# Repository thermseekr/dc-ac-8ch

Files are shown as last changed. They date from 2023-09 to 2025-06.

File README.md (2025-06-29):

# DC-AC-8CH

Triac board with 8x 24 VDC inputs and 8x 220 AC outputs.

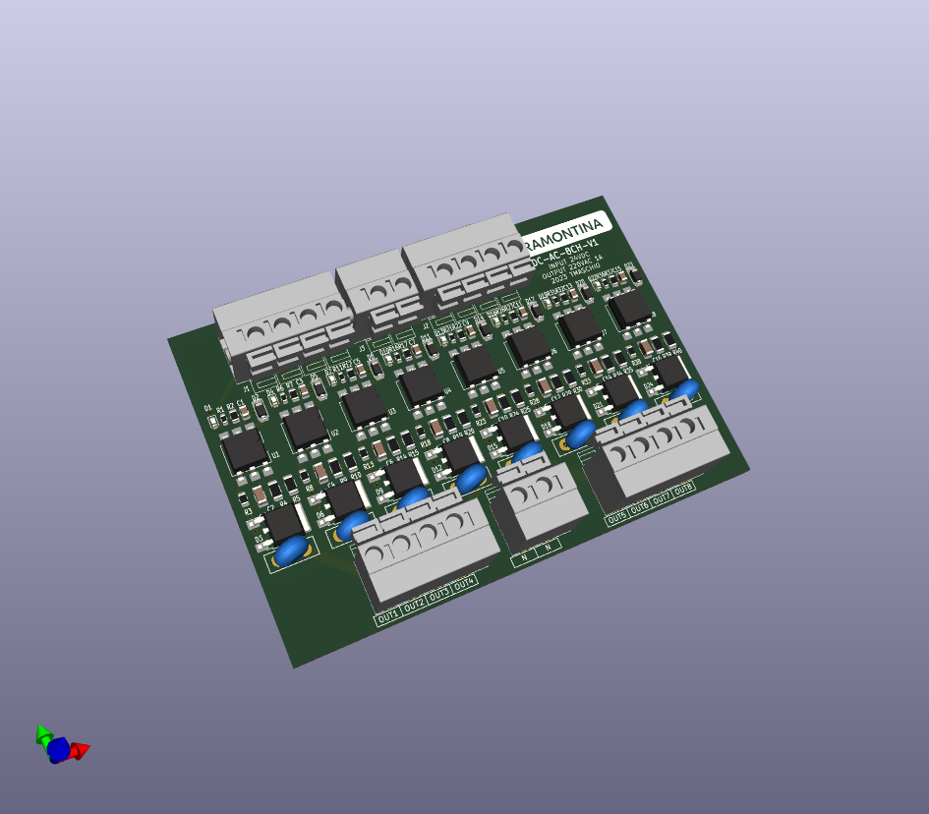
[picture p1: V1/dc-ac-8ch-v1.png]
DC-AC-8CH-V1


## LICENSE

This project is licensed under the [Creative Commons BY-NC 4.0 License](https://creativecommons.org/licenses/by-nc/4.0/).
Commercial use is not permitted without prior written consent. See the [LICENSE.txt](LICENSE.txt) file for details.

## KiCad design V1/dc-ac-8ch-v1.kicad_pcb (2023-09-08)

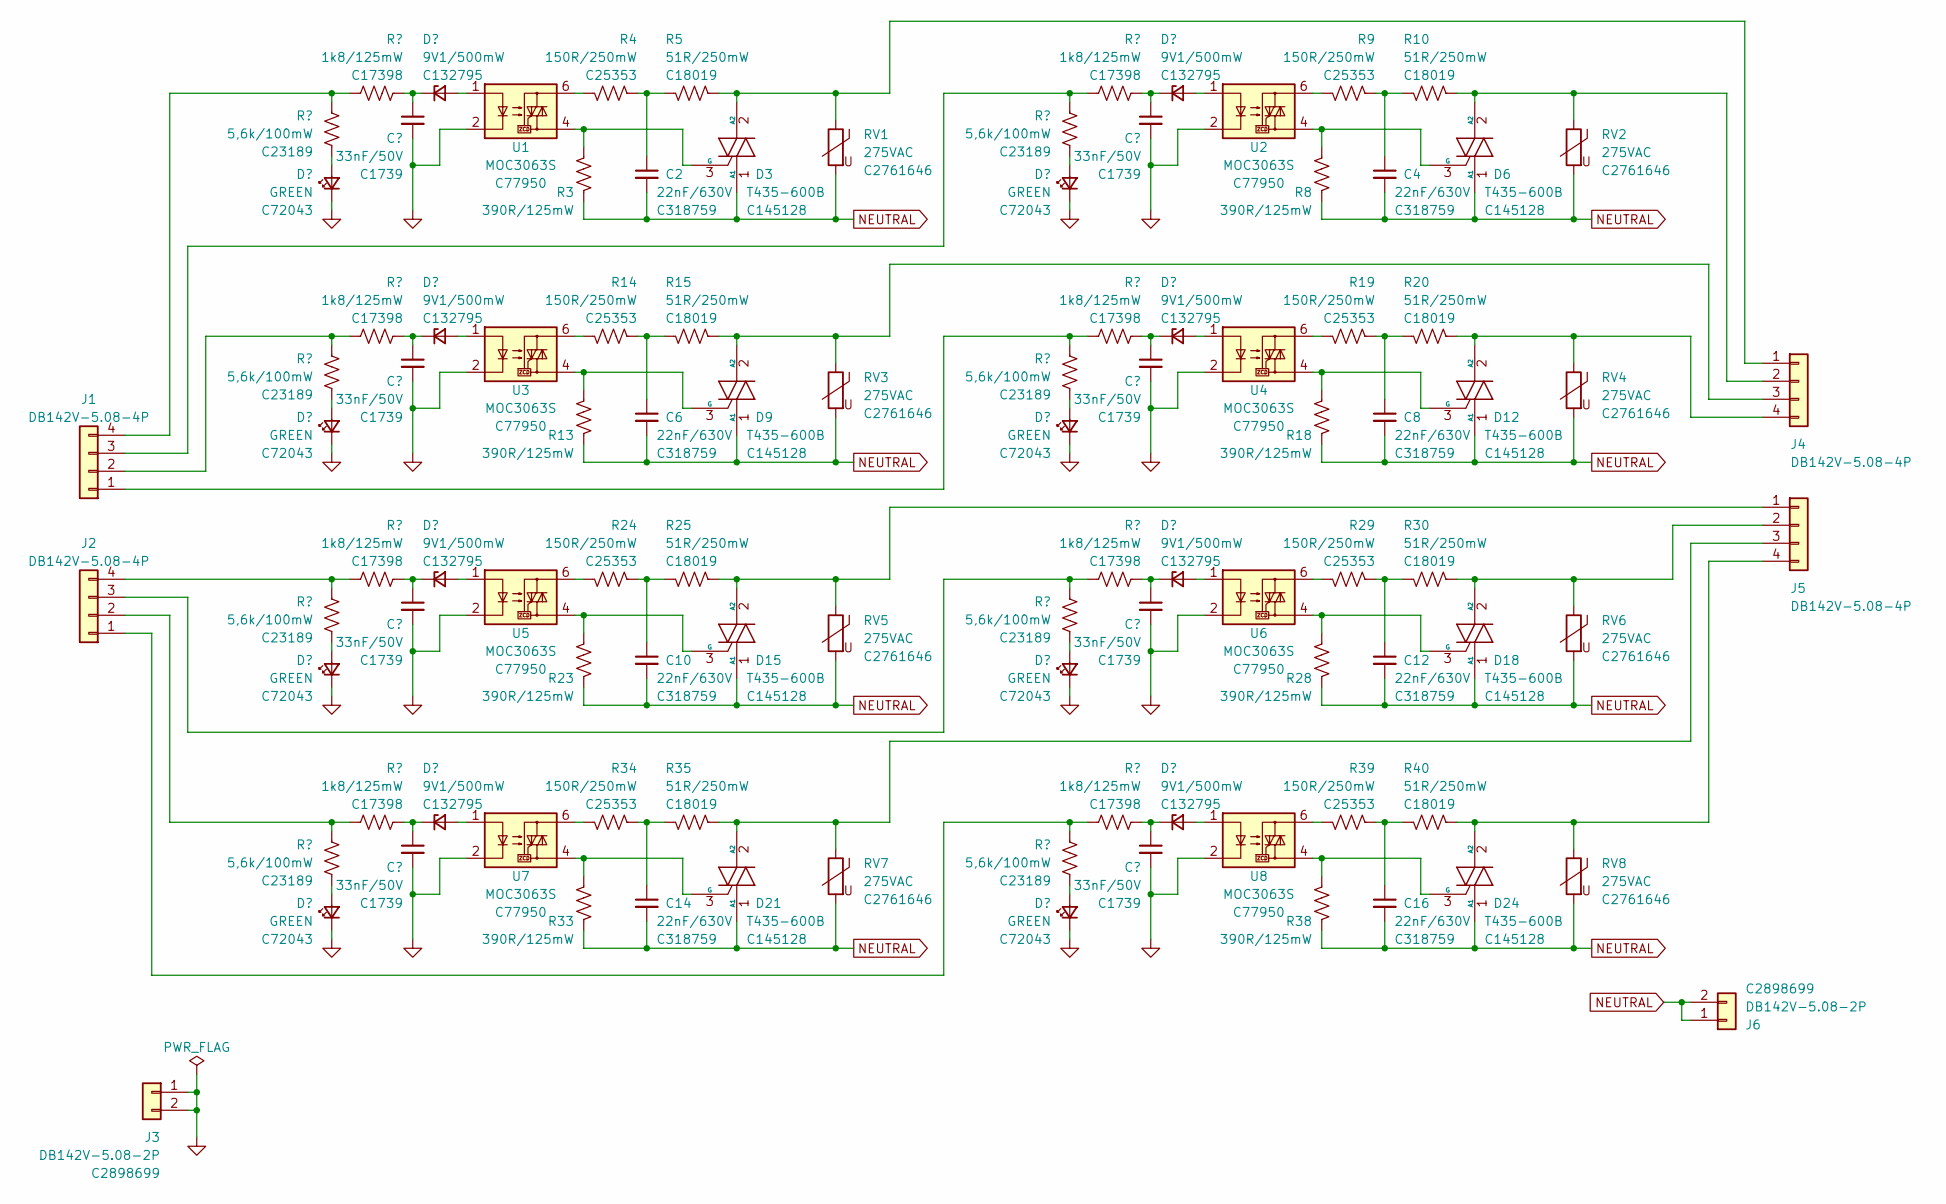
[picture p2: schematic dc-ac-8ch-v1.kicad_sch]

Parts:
C1, C3, C5, C7, C9, C11, C13, C15: 33nF/50V; C_0805_2012Metric; LCSC Part # C1739
C2, C4, C6, C8, C10, C12, C14, C16: 22nF/630V; C_1206_3216Metric; Mfr Part # CL31B223KHHNNNE; JLCPCB BOM 1
D1, D4, D7, D10, D13, D16, D19, D22: GREEN; LED_0603_1608Metric; Mfr Part # 19-217/GHC-YR1S2/3T; LCSC Part # C72043
D2, D5, D8, D11, D14, D17, D20, D23: 9V1/500mW; D_SOD-123; Mfr Part # MMSZ9V1T1G; JLCPCB BOM 1
D3, D6, D9, D12, D15, D18, D21, D24: T435-600B; TO-252-2; Mfr Part # T435-600B-TR; JLCPCB BOM 1
J1, J2, J4, J5: DB142V-5.08-4P; TerminalBlock_Dibo_DB142V-5.08-4P_1x04_P5.08mm_Vertical; Mfr Part # DB142V-5.08-4P; JLCPCB BOM 1
J3, J6: DB142V-5.08-2P; TerminalBlock_Dibo_DB142V-5.08-2P_1x02_P5.08mm_Vertical; Mfr Part # DB142V-5.08-2P; JLCPCB BOM 1
R1, R6, R11, R16, R21, R26, R31, R36: 5,6k/100mW; R_0603_1608Metric; Mfr Part # 0603WAF5601T5E; LCSC Part # C23189
R2, R7, R12, R17, R22, R27, R32, R37: 1k8/125mW; R_0805_2012Metric; Mfr Part # 0805W8F1801T5E; LCSC Part # C17398
R3, R8, R13, R18, R23, R28, R33, R38: 390R/125mW; R_0805_2012Metric; Mfr Part # 0805W8F3900T5E; JLCPCB BOM 1
R4, R9, R14, R19, R24, R29, R34, R39: 150R/250mW; R_1206_3216Metric; Mfr Part # 1206W4J0151T5E; JLCPCB BOM 1
R5, R10, R15, R20, R25, R30, R35, R40: 51R/250mW; R_1206_3216Metric; Mfr Part # 1206W4F510JT5E; JLCPCB BOM 1
RV1, RV2, RV3, RV4, RV5, RV6, RV7, RV8: 275VAC; RV_Disc_D9.50mm_W3.6mm_P5.08mm; Mfr Part # RM07D431KC1IE100; JLCPCB BOM 1
U1, U2, U3, U4, U5, U6, U7, U8: MOC3063S; SMDIP-6_W9.53mm_Clearance8mm; Mfr Part # MOC3063S-TA1; JLCPCB BOM 1

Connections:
GND: C1.2, C3.2, C5.2, C7.2, C9.2, C11.2, C13.2, C15.2, D1.1 (K), D4.1 (K), D7.1 (K), D10.1 (K), D13.1 (K), D16.1 (K), D19.1 (K), D22.1 (K), J3.1, J3.2, U1.2, U2.2, U3.2, U4.2, U5.2, U6.2, U7.2, U8.2
NEUTRAL: C2.2, C4.2, C6.2, C8.2, C10.2, C12.2, C14.2, C16.2, D3.1 (A1), D6.1 (A1), D9.1 (A1), D12.1 (A1), D15.1 (A1), D18.1 (A1), D21.1 (A1), D24.1 (A1), J6.1, J6.2, R3.2, R8.2, R13.2, R18.2, R23.2, R28.2, R33.2, R38.2, RV1.2, RV2.2, RV3.2, RV4.2, RV5.2, RV6.2, RV7.2, RV8.2
unnamed: C2.1, R4.1, R5.2
unnamed: C4.1, R9.1, R10.2
unnamed: C6.1, R14.1, R15.2
unnamed: C8.1, R19.1, R20.2
unnamed: C10.1, R24.1, R25.2
unnamed: C12.1, R29.1, R30.2
unnamed: C14.1, R34.1, R35.2
unnamed: C16.1, R39.1, R40.2
unnamed: D1.2 (A), R1.2
unnamed: D2.2 (A), U1.1
unnamed: C1.1, D2.1 (K), R2.1
unnamed: D3.2 (A2), J4.1, R5.1, RV1.1
unnamed: D3.3 (G), R3.1, U1.4
unnamed: D4.2 (A), R6.2
unnamed: D5.2 (A), U2.1
unnamed: C3.1, D5.1 (K), R7.1
unnamed: D6.2 (A2), J4.2, R10.1, RV2.1
unnamed: D6.3 (G), R8.1, U2.4
unnamed: D7.2 (A), R11.2
unnamed: D8.2 (A), U3.1
unnamed: C5.1, D8.1 (K), R12.1
unnamed: D9.2 (A2), J4.3, R15.1, RV3.1
unnamed: D9.3 (G), R13.1, U3.4
unnamed: D10.2 (A), R16.2
unnamed: D11.2 (A), U4.1
unnamed: C7.1, D11.1 (K), R17.1
unnamed: D12.2 (A2), J4.4, R20.1, RV4.1
unnamed: D12.3 (G), R18.1, U4.4
unnamed: D13.2 (A), R21.2
unnamed: D14.2 (A), U5.1
unnamed: C9.1, D14.1 (K), R22.1
unnamed: D15.2 (A2), J5.1, R25.1, RV5.1
unnamed: D15.3 (G), R23.1, U5.4
unnamed: D16.2 (A), R26.2
unnamed: D17.2 (A), U6.1
unnamed: C11.1, D17.1 (K), R27.1
unnamed: D18.2 (A2), J5.2, R30.1, RV6.1
unnamed: D18.3 (G), R28.1, U6.4
unnamed: D19.2 (A), R31.2
unnamed: D20.2 (A), U7.1
unnamed: C13.1, D20.1 (K), R32.1
unnamed: D21.2 (A2), J5.3, R35.1, RV7.1
unnamed: D21.3 (G), R33.1, U7.4
unnamed: D22.2 (A), R36.2
unnamed: D23.2 (A), U8.1
unnamed: C15.1, D23.1 (K), R37.1
unnamed: D24.2 (A2), J5.4, R40.1, RV8.1
unnamed: D24.3 (G), R38.1, U8.4
unnamed: J1.1, R16.1, R17.2
unnamed: J1.2, R11.1, R12.2
unnamed: J1.3, R6.1, R7.2
unnamed: J1.4, R1.1, R2.2
unnamed: J2.1, R36.1, R37.2
unnamed: J2.2, R31.1, R32.2
unnamed: J2.3, R26.1, R27.2
unnamed: J2.4, R21.1, R22.2
unnamed: R4.2, U1.6
unnamed: R9.2, U2.6
unnamed: R14.2, U3.6
unnamed: R19.2, U4.6
unnamed: R24.2, U5.6
unnamed: R29.2, U6.6
unnamed: R34.2, U7.6
unnamed: R39.2, U8.6

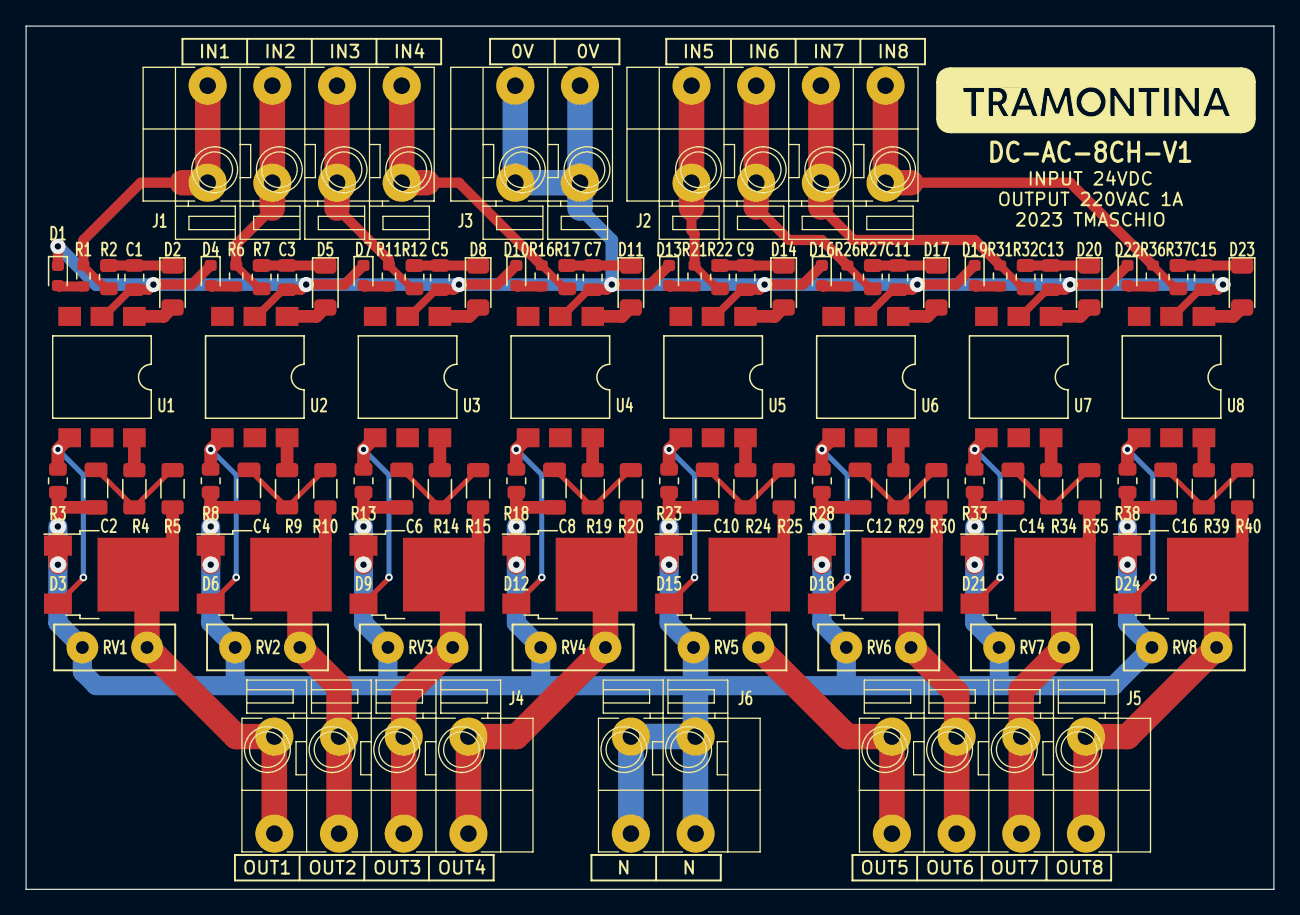
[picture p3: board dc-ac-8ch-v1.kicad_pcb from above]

Board: 2 copper layers, 98.0 x 67.8 mm, 102 parts (0 on the bottom side), 66 nets.

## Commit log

2023-08-31 New design
    [dc-ac-8ch-v1.kicad_pcb, dc-ac-8ch-v1.kicad_sch]
2023-08-31 Circuit under dev
    [dc-ac-8ch-v1.kicad_sch]
2023-08-31 Under development
    [dc-ac-8ch-v1.kicad_pcb, dc-ac-8ch-v1.kicad_sch]
2023-09-01 Zener diode replaced
    [dc-ac-8ch-v1.kicad_pcb, dc-ac-8ch-v1.kicad_sch]
2023-09-01 Replace resistor for basic part
    [dc-ac-8ch-v1.kicad_pcb, dc-ac-8ch-v1.kicad_sch]
2023-09-04 Layout redone, footprints updated
    [dc-ac-8ch-v1.kicad_pcb, dc-ac-8ch-v1.kicad_sch]
2023-09-04 New board image
2023-09-05 Updated image
    [dc-ac-8ch-v1.kicad_pcb]
2023-09-06 Place missing track under zone
    [dc-ac-8ch-v1.kicad_pcb]
2023-09-08 Relocate track
    [dc-ac-8ch-v1.kicad_pcb]
2023-09-08 Repo cleanup
    [dc-ac-8ch-v1.kicad_pcb, dc-ac-8ch-v1.kicad_sch]
